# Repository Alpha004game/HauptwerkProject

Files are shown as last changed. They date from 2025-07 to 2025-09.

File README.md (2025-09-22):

# HauptwerkProject

**STATUS: on going**

Progetto open source per la gestione di una pedaliera MIDI, staffe di espressione e bottoniera compatibili con [Hauptwerk](https://www.hauptwerk.com/), basato su Arduino Pro Micro (ATmega32U4). Il sistema invia messaggi MIDI tramite USB grazie alla libreria `MIDIUSB.h`.

## Contenuto del Progetto

- pedaliera a 30/32 note tramite shift register 74HC165
- **3 Staffe di espressione** analogiche con LED indicatori a segmenti (shift register 74HC595)
- Bottoniera per pedaletti e pulsantini sulle tastiere
- **Output MIDI-USB** compatibile con Hauptwerk, GrandOrgue, o qualsiasi DAW

## Requisiti Hardware

- Arduino Pro Micro (ATmega32U4) – obbligatorio per la libreria MIDIUSB X2
- Shift register 74HC165 (input bottoniera) X8
- Shift register 74HC595 (output LED staffe) X3
- potenziometri lineari o sensori analogici per staffe X3
- contattiera per pedaliera di tipo reed switch o sensori hall X30/x32
- LED per visualizzazione livelli staffa (opzionale) X24

### Librerie Arduino
Assicurati di avere installato:

- [`MIDIUSB`](https://github.com/arduino-libraries/MIDIUSB) (via Library Manager)

## 👤 Autore

**Francesco Patti**  
[GitHub](https://github.com/Alpha004game)

🔗 *Compatibile con Hauptwerk™, GrandOrgue, Reaper, Kontakt, e qualsiasi DAW/MIDI host.*

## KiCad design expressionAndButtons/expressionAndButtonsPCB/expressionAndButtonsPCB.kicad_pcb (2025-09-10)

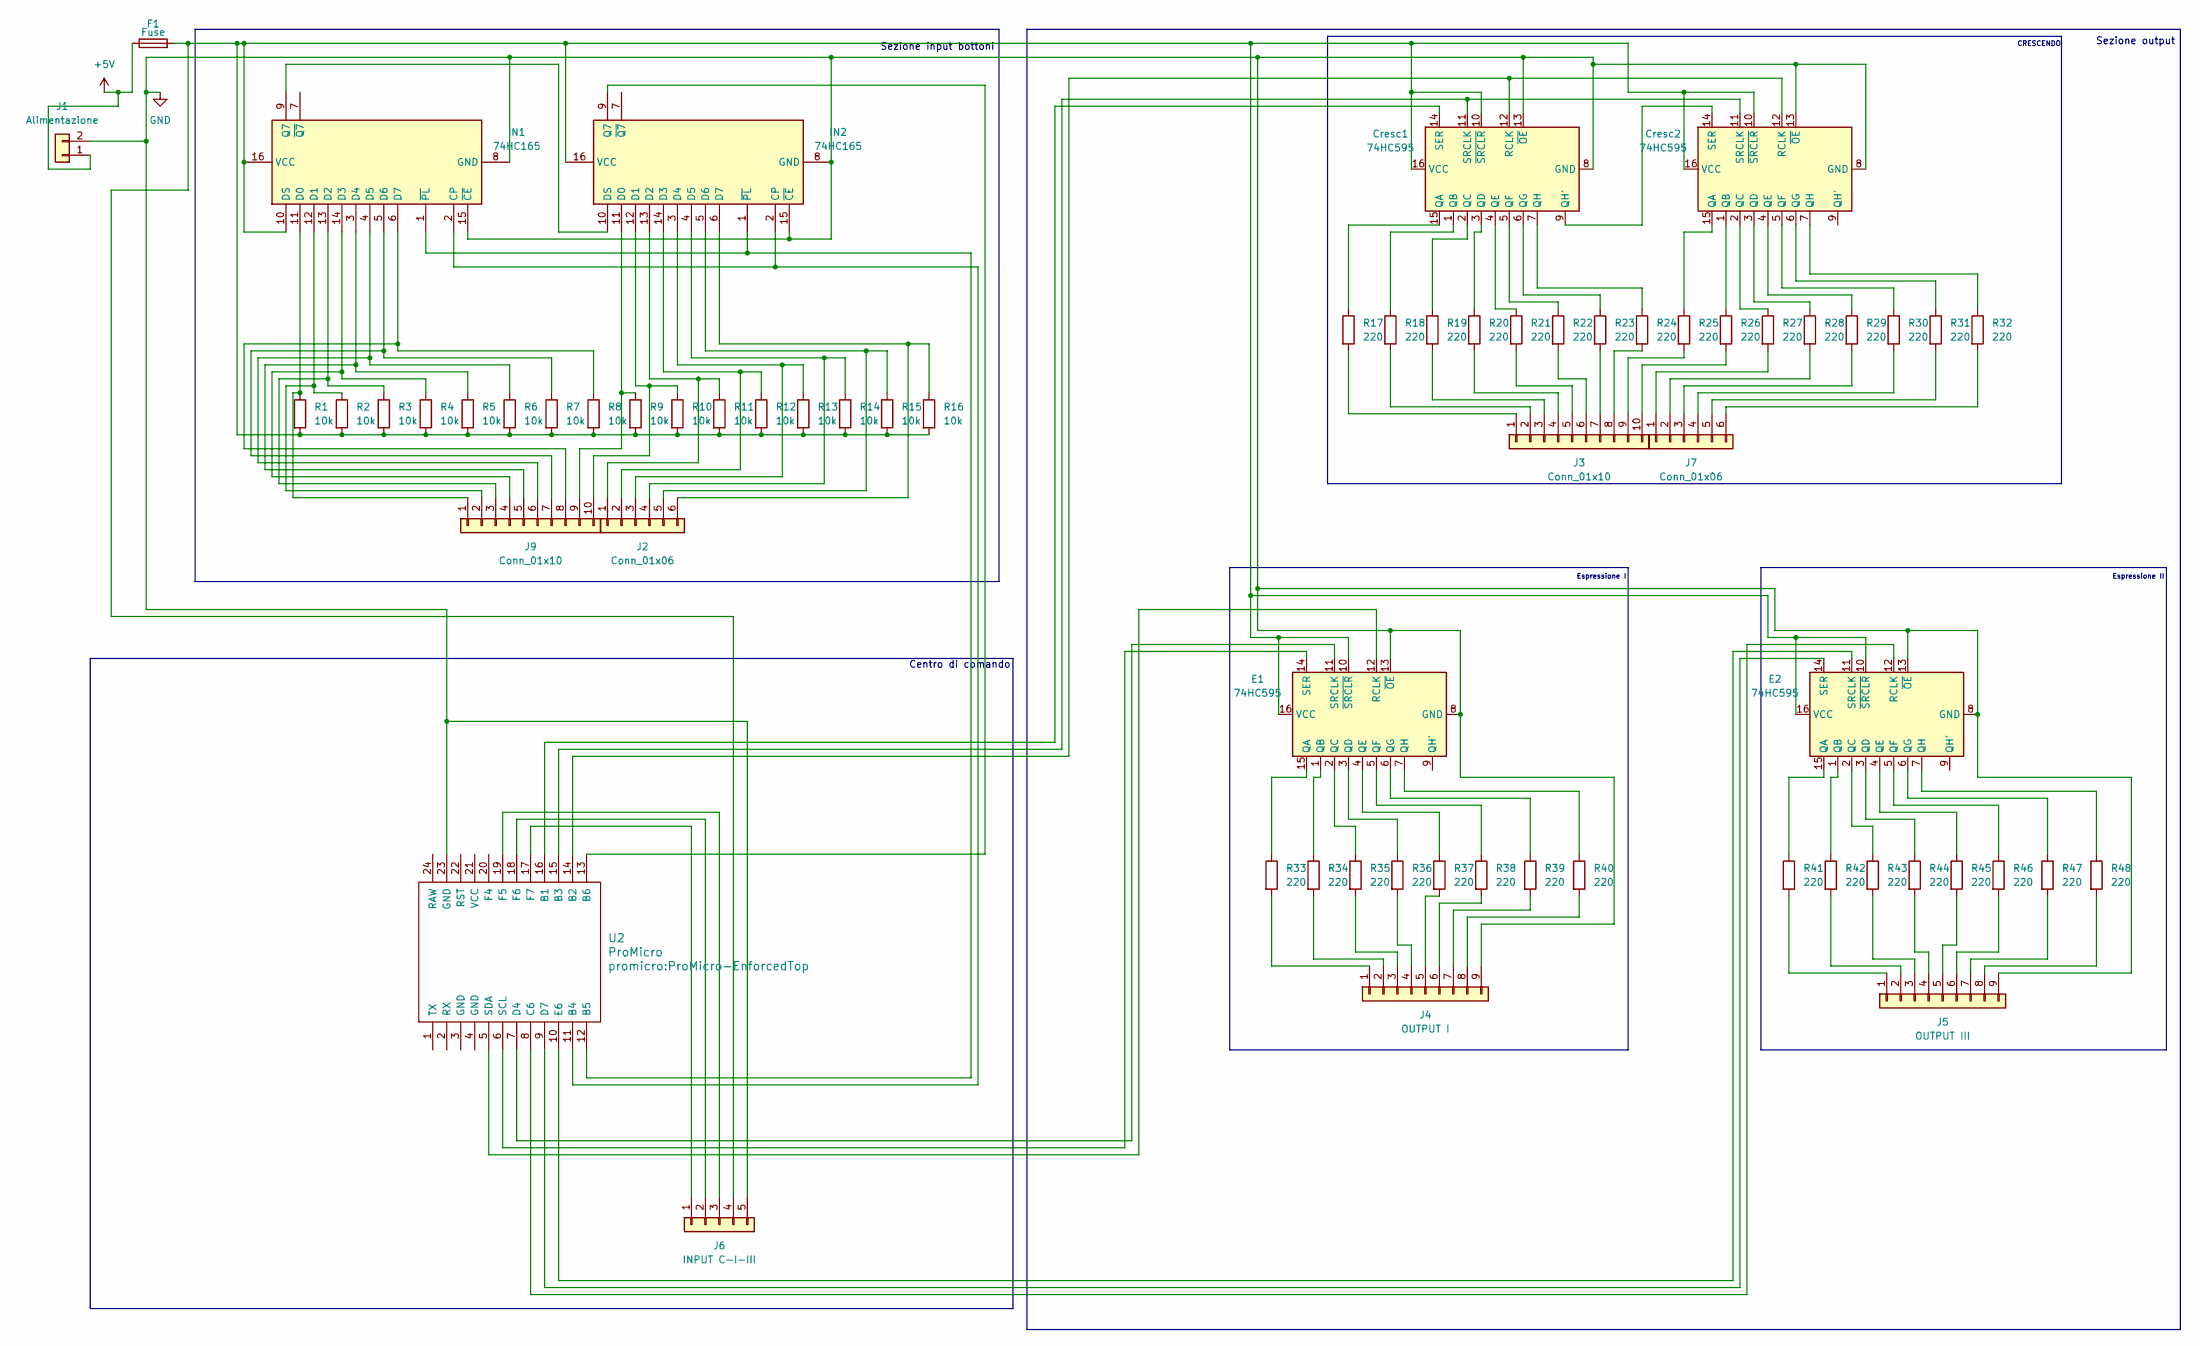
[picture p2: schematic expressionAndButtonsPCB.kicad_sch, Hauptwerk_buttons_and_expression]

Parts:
Cresc1, Cresc2: 74HC595; DIP-16_W7.62mm
E1, E2: 74HC595; DIP-16_W7.62mm
F1: Fuse; Fuseholder_Cylinder-5x20mm_Schurter_0031_8201_Horizontal_Op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
IN1, IN2: 74HC165; DIP-16_W7.62mm
J1: Alimentazione; TerminalBlock_Phoenix_MPT-0,5-2-2.54_1x02_P2.54mm_Horizontal
J2, J7: Conn_01x06; TerminalBlock_Phoenix_MPT-0,5-6-2.54_1x06_P2.54mm_Horizontal
J3, J9: Conn_01x10; TerminalBlock_Phoenix_MPT-0,5-10-2.54_1x10_P2.54mm_Horizont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
J4: OUTPUT I; TerminalBlock_Phoenix_MPT-0,5-9-2.54_1x09_P2.54mm_Horizontal
J5: OUTPUT III; TerminalBlock_Phoenix_MPT-0,5-9-2.54_1x09_P2.54mm_Horizontal
J6: INPUT C-I-III; TerminalBlock_Phoenix_MPT-0,5-5-2.54_1x05_P2.54mm_Horizontal
R1, R2, R3, R4, R5, R6, R7, R8, R9, R10, R11, R12, R13, R14, R15, R16: 10k; R_Axial_DIN0207_L6.3mm_D2.5mm_P7.62mm_Horizontal
R17, R18, R19, R20, R21, R22, R23, R24, R25, R26, R27, R28, R29, R30, R31, R32, R33, R34, R35, R36, R37, R38, R39, R40, R41, R42, R43, R44, R45, R46, R47, R48: 220; R_Axial_DIN0207_L6.3mm_D2.5mm_P7.62mm_Horizontal
U2: ProMicro; ProMicro-EnforcedTop

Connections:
+5V: F1.1, J1.1
GND: Cresc1.8 (GND), Cresc1.13 (~OE), Cresc2.8 (GND), Cresc2.13 (~OE), E1.8 (GND), E1.13 (~OE), E2.8 (GND), E2.13 (~OE), IN1.8 (GND), IN1.15 (~CE), IN2.8 (GND), IN2.15 (~CE), J1.2, J4.9, J5.9, J6.5, U2.23 (GND)
unnamed: Cresc1.15 (QA), R17.1
unnamed: Cresc1.1 (QB), R18.1
unnamed: Cresc1.2 (QC), R19.1
unnamed: Cresc1.3 (QD), R20.1
unnamed: Cresc1.4 (QE), R21.1
unnamed: Cresc1.5 (QF), R22.1
unnamed: Cresc1.6 (QG), R23.1
unnamed: Cresc1.9 (QH'), Cresc2.14 (SER)
unnamed: Cresc1.7 (QH), R24.1
unnamed: Cresc1.12 (RCLK), Cresc2.12 (RCLK), U2.14 (B2)
unnamed: Cresc1.14 (SER), U2.16 (B1)
unnamed: Cresc1.11 (SRCLK), Cresc2.11 (SRCLK), U2.15 (B3)
unnamed: Cresc1.10 (~SRCLR), Cresc1.16 (VCC), Cresc2.10 (~SRCLR), Cresc2.16 (VCC), E1.10 (~SRCLR), E1.16 (VCC), E2.10 (~SRCLR), E2.16 (VCC), F1.2, IN1.10 (DS), IN1.16 (VCC), IN2.16 (VCC), J6.4, R1.2, R2.2, R3.2, R4.2, R5.2, R6.2, R7.2, R8.2, R9.2, R10.2, R11.2, R12.2, R13.2, R14.2, R15.2, R16.2
unnamed: Cresc2.15 (QA), R25.1
unnamed: Cresc2.1 (QB), R26.1
unnamed: Cresc2.2 (QC), R27.1
unnamed: Cresc2.3 (QD), R28.1
unnamed: Cresc2.4 (QE), R29.1
unnamed: Cresc2.5 (QF), R30.1
unnamed: Cresc2.6 (QG), R31.1
unnamed: Cresc2.7 (QH), R32.1
unnamed: E1.15 (QA), R33.1
unnamed: E1.1 (QB), R34.1
unnamed: E1.2 (QC), R35.1
unnamed: E1.3 (QD), R36.1
unnamed: E1.4 (QE), R37.1
unnamed: E1.5 (QF), R38.1
unnamed: E1.6 (QG), R39.1
unnamed: E1.7 (QH), R40.1
unnamed: E1.12 (RCLK), U2.5 (SDA)
unnamed: E1.14 (SER), U2.6 (SCL)
unnamed: E1.11 (SRCLK), U2.7 (D4)
unnamed: E2.15 (QA), R41.1
unnamed: E2.1 (QB), R42.1
unnamed: E2.2 (QC), R43.1
unnamed: E2.3 (QD), R44.1
unnamed: E2.4 (QE), R45.1
unnamed: E2.5 (QF), R46.1
unnamed: E2.6 (QG), R47.1
unnamed: E2.7 (QH), R48.1
unnamed: E2.12 (RCLK), U2.8 (C6)
unnamed: E2.14 (SER), U2.9 (D7)
unnamed: E2.11 (SRCLK), U2.10 (E6)
unnamed: IN1.2 (CP), IN2.2 (CP), U2.11 (B4)
unnamed: IN1.11 (D0), J9.1, R1.1
unnamed: IN1.12 (D1), J9.2, R2.1
unnamed: IN1.13 (D2), J9.3, R3.1
unnamed: IN1.14 (D3), J9.4, R4.1
unnamed: IN1.3 (D4), J9.5, R5.1
unnamed: IN1.4 (D5), J9.6, R6.1
unnamed: IN1.5 (D6), J9.7, R7.1
unnamed: IN1.6 (D7), J9.8, R8.1
unnamed: IN1.9 (Q7), IN2.10 (DS)
unnamed: IN1.1 (~PL), IN2.1 (~PL), U2.12 (B5)
unnamed: IN2.11 (D0), J9.9, R9.1
unnamed: IN2.12 (D1), J9.10, R10.1
unnamed: IN2.13 (D2), J2.1, R11.1
unnamed: IN2.14 (D3), J2.2, R12.1
unnamed: IN2.3 (D4), J2.3, R13.1
unnamed: IN2.4 (D5), J2.4, R14.1
unnamed: IN2.5 (D6), J2.5, R15.1
unnamed: IN2.6 (D7), J2.6, R16.1
unnamed: IN2.9 (Q7), U2.13 (B6)
unnamed: J3.1, R17.2
unnamed: J3.2, R18.2
unnamed: J3.3, R19.2
unnamed: J3.4, R20.2
unnamed: J3.5, R21.2
unnamed: J3.6, R22.2
unnamed: J3.7, R23.2
unnamed: J3.8, R24.2
unnamed: J3.9, R25.2
unnamed: J3.10, R26.2
unnamed: J4.1, R33.2
unnamed: J4.2, R34.2
unnamed: J4.3, R35.2
unnamed: J4.4, R36.2
unnamed: J4.5, R37.2
unnamed: J4.6, R38.2
unnamed: J4.7, R39.2
unnamed: J4.8, R40.2
unnamed: J5.1, R41.2
unnamed: J5.2, R42.2
unnamed: J5.3, R43.2
unnamed: J5.4, R44.2
unnamed: J5.5, R45.2
unnamed: J5.6, R46.2
unnamed: J5.7, R47.2
unnamed: J5.8, R48.2
unnamed: J6.1, U2.17 (F7)
unnamed: J6.2, U2.18 (F6)
unnamed: J6.3, U2.19 (F5)
unnamed: J7.1, R27.2
unnamed: J7.2, R28.2
unnamed: J7.3, R29.2
unnamed: J7.4, R30.2
unnamed: J7.5, R31.2
unnamed: J7.6, R32.2

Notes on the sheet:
Espressione I
CRESCENDO
Sezione output
Centro di comando
Sezione input bottoni
Espressione II

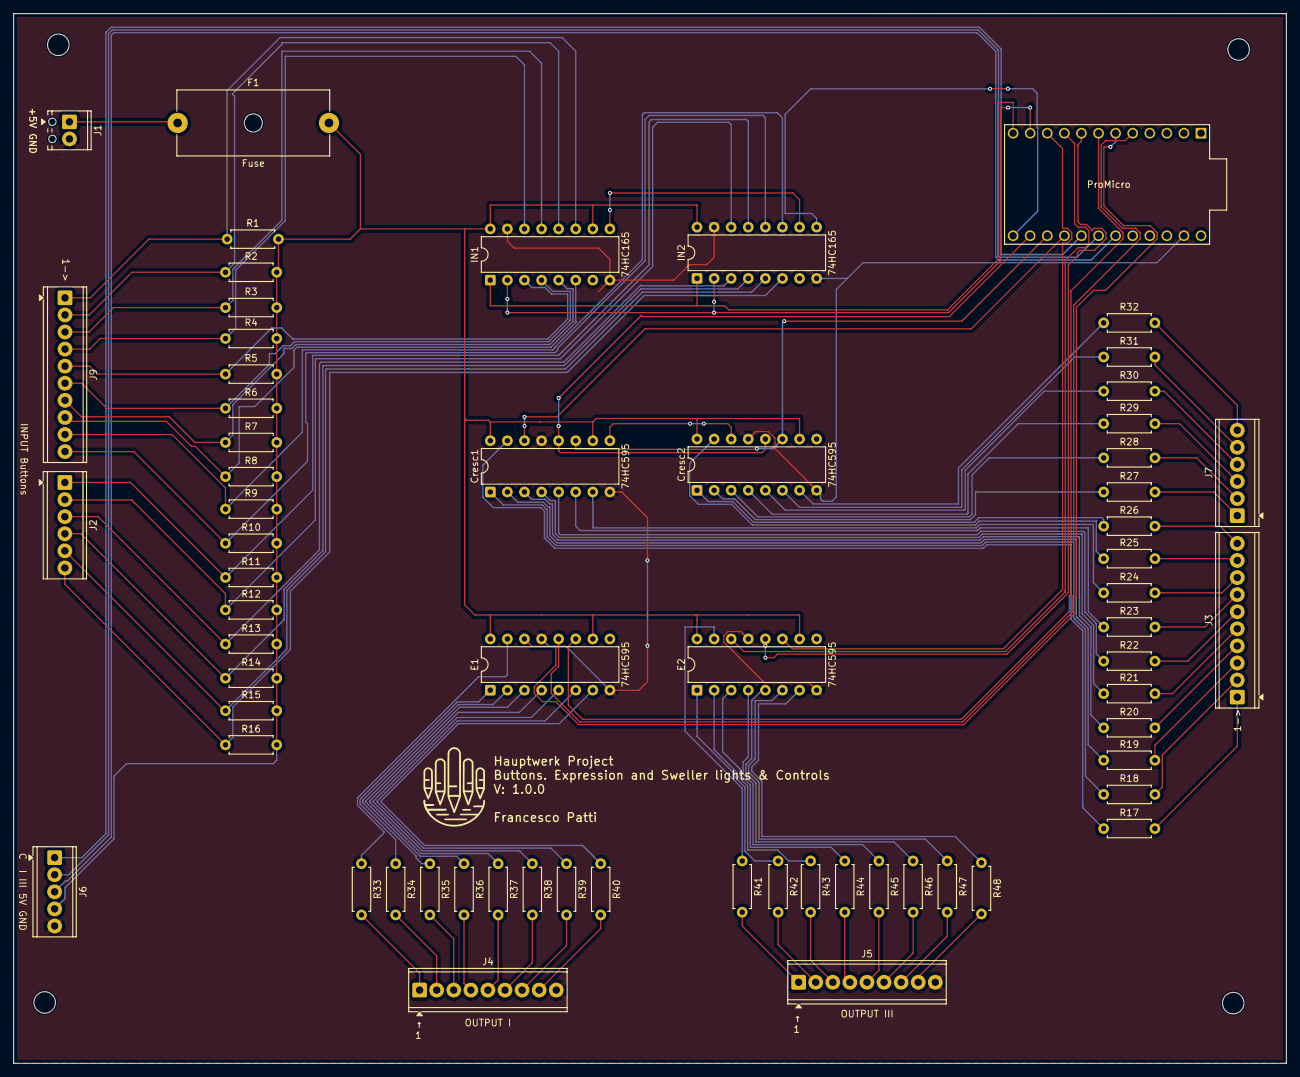
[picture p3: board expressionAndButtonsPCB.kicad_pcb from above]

Board: 2 copper layers, 189.2 x 156.1 mm, 64 parts (0 on the bottom side), 100 nets.

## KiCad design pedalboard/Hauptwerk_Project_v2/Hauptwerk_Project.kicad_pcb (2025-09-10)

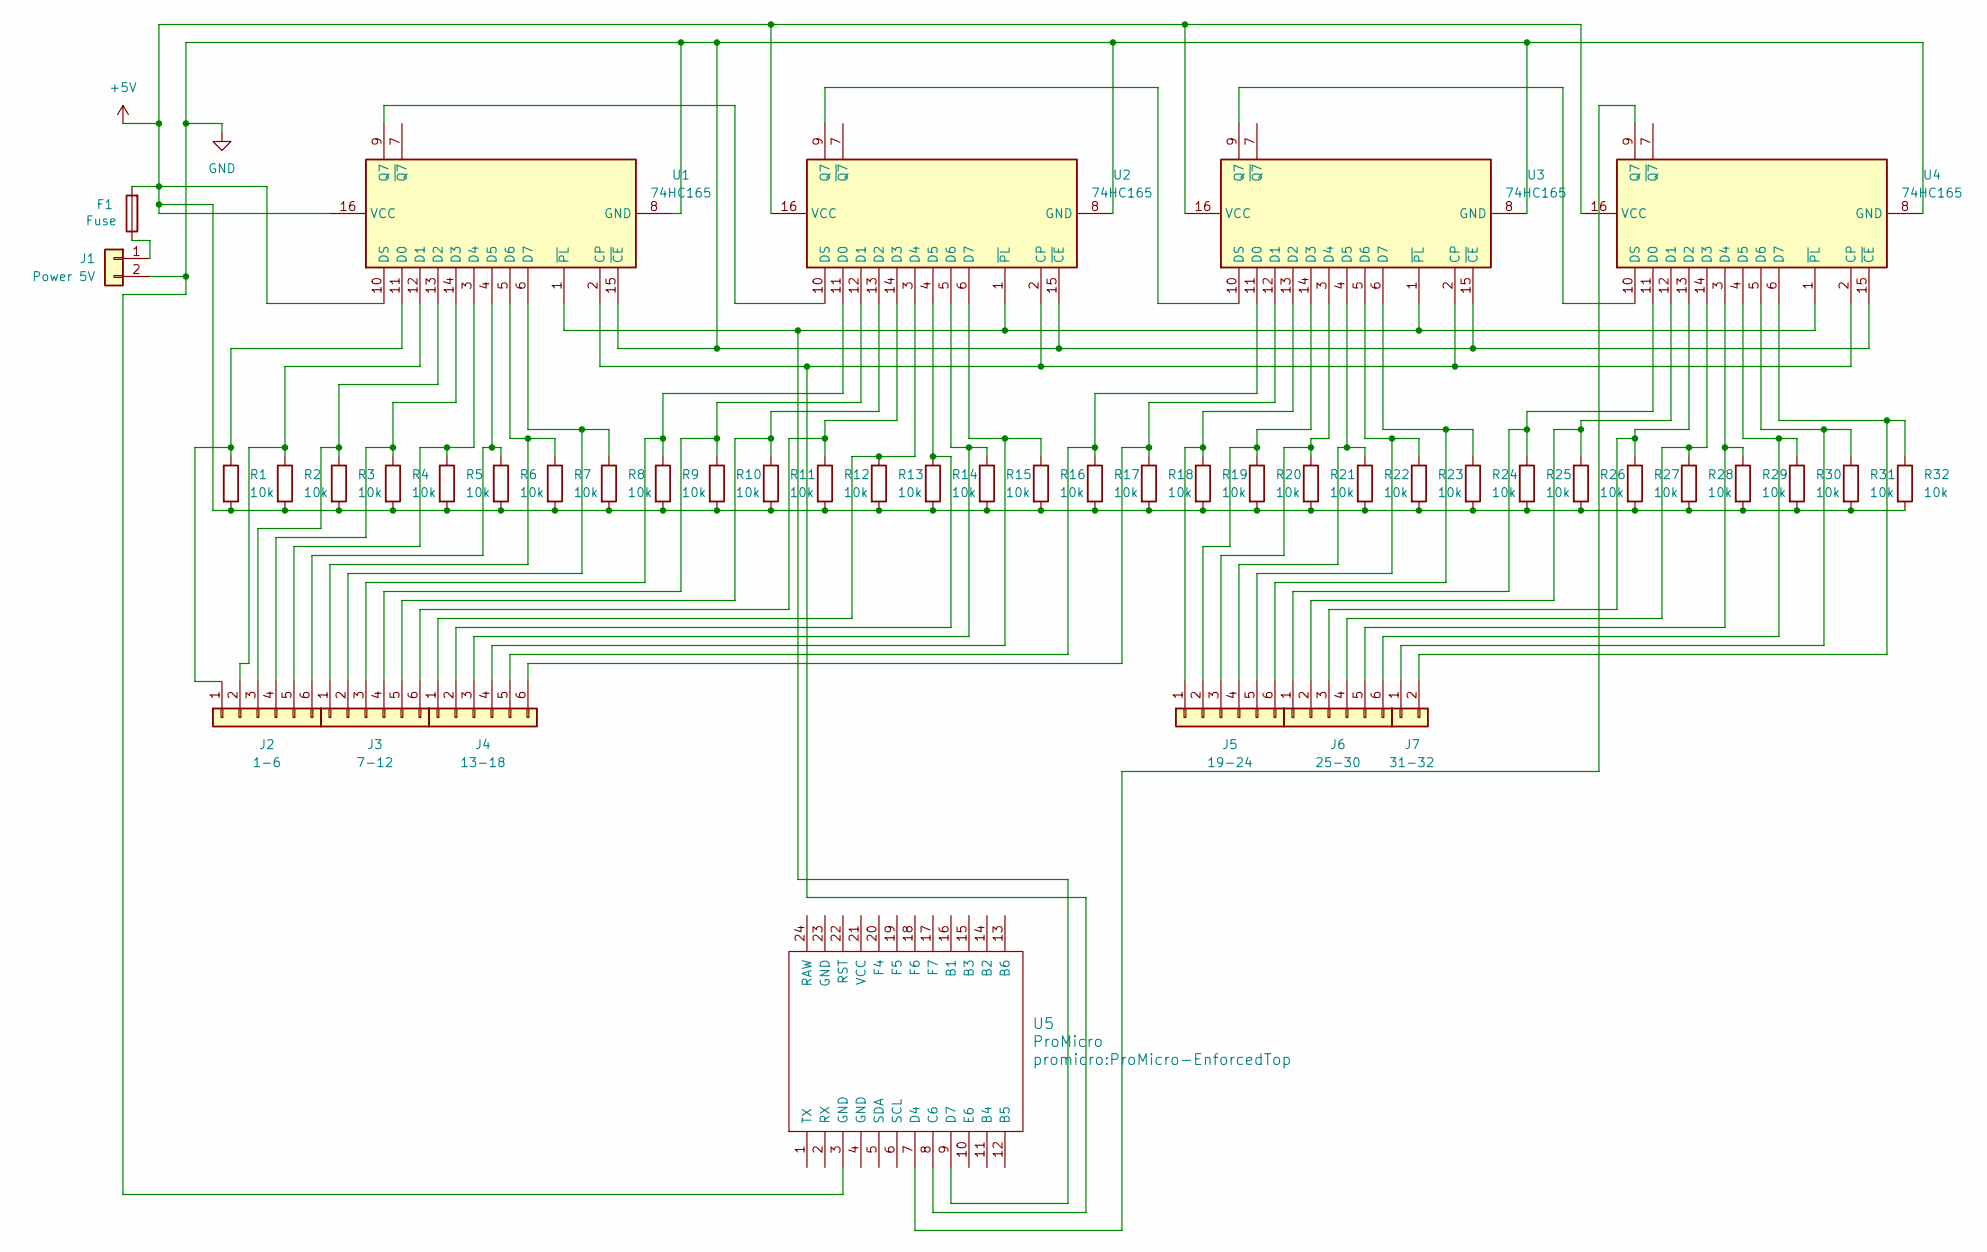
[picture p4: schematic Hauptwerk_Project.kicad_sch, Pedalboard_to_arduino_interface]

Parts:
F1: Fuse; Fuseholder_Cylinder-5x20mm_Schurter_0031_8201_Horizontal_Op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
J1: Power 5V; TerminalBlock_Phoenix_MKDS-1,5-2-5.08_1x02_P5.08mm_Horizont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
J2: 1-6; TerminalBlock_Phoenix_MKDS-1,5-6-5.08_1x06_P5.08mm_Horizont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
J3: 7-12; TerminalBlock_Phoenix_MKDS-1,5-6-5.08_1x06_P5.08mm_Horizont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
J4: 13-18; TerminalBlock_Phoenix_MKDS-1,5-6-5.08_1x06_P5.08mm_Horizont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
J5: 19-24; TerminalBlock_Phoenix_MKDS-1,5-6-5.08_1x06_P5.08mm_Horizont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
J6: 25-30; TerminalBlock_Phoenix_MKDS-1,5-6-5.08_1x06_P5.08mm_Horizont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
J7: 31-32; TerminalBlock_Phoenix_MKDS-1,5-2-5.08_1x02_P5.08mm_Horizont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
R1, R2, R3, R4, R5, R6, R7, R8, R9, R10, R11, R12, R13, R14, R15, R16, R17, R18, R19, R20, R21, R22, R23, R24, R25, R26, R27, R28, R29, R30, R31, R32: 10k; R_Axial_DIN0207_L6.3mm_D2.5mm_P7.62mm_Horizontal
U1, U2, U3, U4: 74HC165; DIP-16_W7.62mm
U5: ProMicro; ProMicro-EnforcedTop

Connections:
+5V: F1.2, R1.2, R2.2, R3.2, R4.2, R5.2, R6.2, R7.2, R8.2, R9.2, R10.2, R11.2, R12.2, R13.2, R14.2, R15.2, R16.2, R17.2, R18.2, R19.2, R20.2, R21.2, R22.2, R23.2, R24.2, R25.2, R26.2, R27.2, R28.2, R29.2, R30.2, R31.2, R32.2, U1.10 (DS), U1.16 (VCC), U2.16 (VCC), U3.16 (VCC), U4.16 (VCC)
GND: J1.2, U1.8 (GND), U1.15 (~CE), U2.8 (GND), U2.15 (~CE), U3.8 (GND), U3.15 (~CE), U4.8 (GND), U4.15 (~CE), U5.3 (GND)
unnamed: F1.1, J1.1
unnamed: J2.1, R1.1, U1.11 (D0)
unnamed: J2.2, R2.1, U1.12 (D1)
unnamed: J2.3, R3.1, U1.13 (D2)
unnamed: J2.4, R4.1, U1.14 (D3)
unnamed: J2.5, R5.1, U1.3 (D4)
unnamed: J2.6, R6.1, U1.4 (D5)
unnamed: J3.1, R7.1, U1.5 (D6)
unnamed: J3.2, R8.1, U1.6 (D7)
unnamed: J3.3, R9.1, U2.11 (D0)
unnamed: J3.4, R10.1, U2.12 (D1)
unnamed: J3.5, R11.1, U2.13 (D2)
unnamed: J3.6, R12.1, U2.14 (D3)
unnamed: J4.1, R13.1, U2.3 (D4)
unnamed: J4.2, R14.1, U2.4 (D5)
unnamed: J4.3, R15.1, U2.5 (D6)
unnamed: J4.4, R16.1, U2.6 (D7)
unnamed: J4.5, R17.1, U3.11 (D0)
unnamed: J4.6, R18.1, U3.12 (D1)
unnamed: J5.1, R19.1, U3.13 (D2)
unnamed: J5.2, R20.1, U3.14 (D3)
unnamed: J5.3, R21.1, U3.3 (D4)
unnamed: J5.4, R22.1, U3.4 (D5)
unnamed: J5.5, R23.1, U3.5 (D6)
unnamed: J5.6, R24.1, U3.6 (D7)
unnamed: J6.1, R25.1, U4.11 (D0)
unnamed: J6.2, R26.1, U4.12 (D1)
unnamed: J6.3, R27.1, U4.13 (D2)
unnamed: J6.4, R28.1, U4.14 (D3)
unnamed: J6.5, R29.1, U4.3 (D4)
unnamed: J6.6, R30.1, U4.4 (D5)
unnamed: J7.1, R31.1, U4.5 (D6)
unnamed: J7.2, R32.1, U4.6 (D7)
unnamed: U1.2 (CP), U2.2 (CP), U3.2 (CP), U4.2 (CP), U5.8 (C6)
unnamed: U1.9 (Q7), U2.10 (DS)
unnamed: U1.1 (~PL), U2.1 (~PL), U3.1 (~PL), U4.1 (~PL), U5.9 (D7)
unnamed: U2.9 (Q7), U3.10 (DS)
unnamed: U3.9 (Q7), U4.10 (DS)
unnamed: U4.9 (Q7), U5.7 (D4)

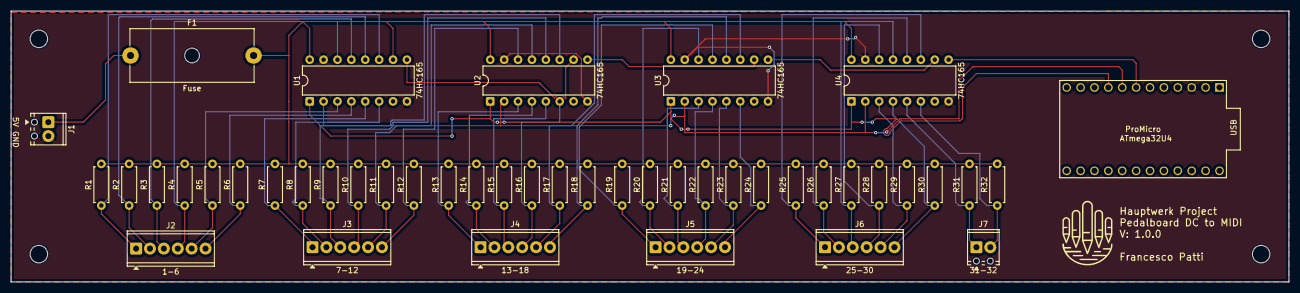
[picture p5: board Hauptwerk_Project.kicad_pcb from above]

Board: 2 copper layers, 233.7 x 49.5 mm, 45 parts (0 on the bottom side), 41 nets.

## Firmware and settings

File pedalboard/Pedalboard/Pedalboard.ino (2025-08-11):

/*
       ---PROGETTO HAUPTWERK---
       Titolo: pedalboardToArduinoToMidi
       Descrizione: Codice necessario al funzionamento della pedaliera (30/32 note)
       Nota: 
       Autore: Francesco Patti
       Versione: 1.5.0
       Arduino: Arduino Pro Micro con 32U4
*/
#include "MIDIUSB.h"

/*   ---MIDI SETTINGS---   */
#define MIDI_CHANNEL 0
#define BASENOTE 36 // Do2 (Calibrare a seconda del funzionamento di hauptwerk)

/*   ----Pedalboard config---   */
#define NUM_CHIPS 4
#define LATCHPIN 6
#define CLOCKPIN 5
#define DATAPIN 4
const int NUM_KEYS = 8 * NUM_CHIPS;

/* ---State memorizer---*/
bool lastState[NUM_KEYS];
byte values[NUM_CHIPS];


void setup() {
  pinMode(LATCHPIN, OUTPUT);
  pinMode(CLOCKPIN, OUTPUT);
  pinMode(DATAPIN, INPUT);

  for (int i = 0; i < NUM_KEYS; i++) {
    lastState[i] = false;
  }

  for(int i=0; i<NUM_CHIPS; i++)
  {
    values[i]=255; //Logica invertita per il PULLUP
  }
}

void loop() {
  digitalWrite(LATCHPIN, LOW);   // Blocca input
  delayMicroseconds(10);
  digitalWrite(LATCHPIN, HIGH);  // Carica i dati
  delayMicroseconds(10);

  // Leggo tutti i chip
  for (int chip = 0; chip < NUM_CHIPS; chip++) {
    //values[chip] = shiftIn(DATAPIN, CLOCKPIN, MSBFIRST);
    values[chip]=readShiftRegister();
  }

  // Ora scorri ogni bit per determinare il singolo stato di ogni pedale
  for (int i = 0; i < NUM_KEYS; i++) {
    int chipIndex = i / 8;
    int bitIndex = 7 - (i % 8);


    bool current = bitRead(values[chipIndex], bitIndex) == 0;

    if (current != lastState[i]) {
      lastState[i] = current;

      int reversedIndex = (NUM_KEYS - 1) - i;

      if (current) {
        noteOn(MIDI_CHANNEL, BASENOTE + reversedIndex, 100);
      } else {
        noteOff(MIDI_CHANNEL, BASENOTE + reversedIndex, 0);
      }

      MidiUSB.flush();
    }
  }
}

void noteOn(byte channel, byte pitch, byte velocity) {
  midiEventPacket_t noteOnMsg = {0x09, 0x90 | channel, pitch, velocity};
  MidiUSB.sendMIDI(noteOnMsg);
}

void noteOff(byte channel, byte pitch, byte velocity) {
  midiEventPacket_t noteOffMsg = {0x08, 0x80 | channel, pitch, velocity};
  MidiUSB.sendMIDI(noteOffMsg);
}

byte readShiftRegister() {
  byte data = 0;
  for (int i = 0; i < 8; i++) {
    data <<= 1;
    data |= digitalRead(DATAPIN);
    digitalWrite(CLOCKPIN, HIGH);
    delayMicroseconds(1);
    digitalWrite(CLOCKPIN, LOW);
    delayMicroseconds(1);
  }
  return data;
}

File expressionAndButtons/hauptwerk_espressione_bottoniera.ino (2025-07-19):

/*
       ---PROGETTO HAUPTWERK---
       Titolo: buttonsAndExpression
       Descrizione: Codice necessario al funzionamento delle staffe e della bottoniera
       Nota: Bottoniera per input PULLUP
       Autore: Francesco Patti
       Versione: 1.0.0
       Arduino: Arduino Pro Micro con 32U4
*/

/*
PEDALETTI DA IMPLEMENTARE

CICCIO:
+
-
10 aggiustabili
P->I, P->II, P->III
I->III
II->I, II->III

TUTTI
Ann gen
Fiss

Totale: 21 (Capire distribuzione tra tastiere e pedaletti)

FABIO:
+
-
10 aggiustabili
P->I, P->II, P->III, P->IV
I->III, I->IV
II->I, II->III, II->IV
III->IV

TUTTI
Ann gen
Fiss

Totale: 25 (Capire distribuizione tra tastiere e pedaletti)


*/

#include "MIDIUSB.h"

/*---Sezione Bottoniera---*/
#define CLOCK_B_PIN 8
#define LATCH_B_PIN 9
#define DATA_B_PIN 10
#define P_CHANNEL 4

#define NUM_CHIPS 4
#define BASENOTE 36 //"Nota" di base per riferimento

const int NUM_BUTTONS = 8 * NUM_CHIPS;
bool lastButtonState[NUM_BUTTONS];
byte buttonValues[NUM_CHIPS];
/*---Fine Sezione Bottoniera---*/



/*---Sezione Espressione---*/
#define EXPRESSION_PIN_1 A0 //Crescendo
#define EXPRESSION_PIN_2 A1 //I (III)
#define EXPRESSION_PIN_3 A2 //III (IV)

int lastValue[3] = {-1, -1, -1};

#define SMOOTHING 4  
#define MIDI_CONTROLLER 11  //Controller

//SW
#define LATCH_C_PIN 14 //ST_CP
#define DATA_C_PIN 15 //DS
#define CLOCK_C_PIN 16 //SH_CP
#define C_CHANNEL 1
#define C_CONTROLLER 19

//I(III)
#define LATCH_E1_PIN 2 
#define DATA_E1_PIN 3
#define CLOCK_E1_PIN 4
#define E1_CHANNEL 2
#define E1_CONTROLLER 4

//III(IV)
#define LATCH_E2_PIN 5
#define DATA_E2_PIN 6
#define CLOCK_E2_PIN 7
#define E2_CHANNEL 3
#define E2_CONTROLLER 11

/*---Fine Sezione Espressione---*/


/*---Commons---*/

/*---Fine Commons---*/

void setup() {
  /*COMMON*/
  
  /*END COMMON*/

  /*BUTTON*/
  pinMode(LATCH_B_PIN, OUTPUT);
  pinMode(CLOCK_B_PIN, OUTPUT);
  pinMode(DATA_B_PIN, INPUT);

  for(int i=0; i<NUM_CHIPS; i++)
  {
    lastButtonState[i]=false;
  }
  for(int i=0; i<NUM_CHIPS; i++)
  {
    buttonValues[i]=255;
  }
  /*END BUTTON*/

  /*EXPRESSION*/
  pinMode(EXPRESSION_PIN_1, INPUT);
  pinMode(EXPRESSION_PIN_2, INPUT);
  pinMode(EXPRESSION_PIN_3, INPUT);

  pinMode(CLOCK_C_PIN, OUTPUT);
  pinMode(LATCH_C_PIN, OUTPUT);
  pinMode(DATA_C_PIN, OUTPUT);
  /*END EXPRESSION*/
}

void loop() {
  updateStaffa(EXPRESSION_PIN_1, CLOCK_C_PIN, LATCH_C_PIN, DATA_C_PIN, C_CHANNEL, C_CONTROLLER);
  updateStaffa(EXPRESSION_PIN_2, CLOCK_E1_PIN, LATCH_E1_PIN, DATA_E1_PIN, E1_CHANNEL, E1_CONTROLLER);
  updateStaffa(EXPRESSION_PIN_3, CLOCK_E2_PIN, LATCH_E2_PIN, DATA_E2_PIN, E2_CHANNEL, E2_CONTROLLER);
  //updateBottoniera(CLOCK_B_PIN, LATCH_B_PIN, DATA_B_PIN, P_CHANNEL);

}

//---------------------------------------------BUTTON-------------------------------------------------------
void updateBottoniera(int clockPin, int latchPin, int dataPin, int midiChannel)
{
  digitalWrite(latchPin, LOW);
  delayMicroseconds(5);
  digitalWrite(latchPin, HIGH);

  for (int i = 0; i < NUM_BUTTONS; i++) {
    buttonValues[i] = shiftIn(dataPin, clockPin, MSBFIRST);
  }

  for (int i = 0; i < NUM_BUTTONS; i++) {
    int chipIndex = i / 8;
    int bitIndex = 7 - (i % 8);

    bool current = bitRead(buttonValues[chipIndex], bitIndex) == 0;

    if (current != lastButtonState[i]) {
      lastButtonState[i] = current;

      if (current) {
        noteOn(midiChannel, BASENOTE + i, 100);
      } else {
        noteOff(midiChannel, BASENOTE + i, 0);
      }

      MidiUSB.flush();
    }
  }
}

void noteOn(byte channel, byte pitch, byte velocity) {
  midiEventPacket_t noteOnMsg = {0x09, 0x90 | channel, pitch, velocity};
  MidiUSB.sendMIDI(noteOnMsg);
}

void noteOff(byte channel, byte pitch, byte velocity) {
  midiEventPacket_t noteOffMsg = {0x08, 0x80 | channel, pitch, velocity};
  MidiUSB.sendMIDI(noteOffMsg);
}
//----------------------------------------------------------------------------------------------------------


//---------------------------------------------EXPRESSION---------------------------------------------------
void updateStaffa(int analogPin, int clockPin, int latchPin, int dataPin, int midiChannel, int controller) {
  int index;
  switch (analogPin) {
    case A0:
      index = 0;
      break;
    case A1:
      index = 1;
      break;
    case A2:
      index = 2;
      break;
  }

  int analogValue = analogRead(analogPin);
  int midiValue = map(analogValue, 0, 1023, 0, 127);

  if (abs(midiValue - lastValue[index]) >= SMOOTHING) {
    lastValue[index] = midiValue;
    
    
    sendControlChange(controller, midiValue, midiChannel);
    updateLuci(clockPin, latchPin, dataPin, midiValue);
  }
}

void updateLuci(int clockPin, int latchPin, int dataPin, int value) {
  byte binaryValue = getBinaryValuePerStaffa(value);

  digitalWrite(latchPin, LOW);
  shiftOut(dataPin, clockPin, MSBFIRST, binaryValue);
  digitalWrite(latchPin, HIGH);
}

byte getBinaryValuePerStaffa(int value) {
  if (value >= 0 && value <= 14) {
    return B00000000;
  } else if (value >= 15 && value <= 29) {
    return B00000001;
  } else if (value >= 30 && value <= 44) {
    return B00000011;
  } else if (value >= 45 && value <= 59) {
    return B00000111;
  } else if (value >= 60 && value <= 74) {
    return B00001111;
  } else if (value >= 75 && value <= 89) {
    return B00011111;
  } else if (value >= 90 && value <= 104) {
    return B00111111;
  } else if (value >= 105 && value <= 112) {
    return B01111111;
  } else {
    return B11111111;
  }
}

void sendControlChange(byte control, byte value, byte channel) {
  midiEventPacket_t event = {0x0B, 0xB0 | channel, control, value};

  MidiUSB.sendMIDI(event);
  MidiUSB.flush();
}


//----------------------------------------------------------------------------------------------------------

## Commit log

2025-07-31 Creazione PCB
    Prima versione creata e qualche sistemazione nello schema elettrico
    [Hauptwerk_Project.kicad_pcb, Hauptwerk_Project.kicad_sch]
2025-08-02 Aggiornamento e creazione versione con arduino integrato
    [Hauptwerk_Project.kicad_pcb, Hauptwerk_Project.kicad_sch]
2025-08-02 Creazione progetto per staffe e bottoniera
    [expressionAndButtonsPCB.kicad_pcb, expressionAndButtonsPCB.kicad_sch]
2025-08-11 Fix vari
    [Hauptwerk_Project-B_Cu.gbr, Hauptwerk_Project-B_Mask.gbr, Hauptwerk_Project-B_Paste.gbr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]
2025-08-28 Update dim footprint
    [Hauptwerk_Project-B_Cu.gbr, Hauptwerk_Project-B_Mask.gbr, Hauptwerk_Project-B_Paste.gbr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]
2025-09-01 Progresso bottoniera
    [Hauptwerk_Project-B_Cu.gbr, Hauptwerk_Project-B_Mask.gbr, Hauptwerk_Project-B_Paste.gbr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]
2025-09-02 First version buttons
    [expressionAndButtonsPCB.kicad_pcb, expressionAndButtonsPCB.kicad_sch]
2025-09-10 problem fix
    [Hauptwerk_Project-B_Cu.gbr, Hauptwerk_Project-B_Mask.gbr, Hauptwerk_Project-B_Paste.gbr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]

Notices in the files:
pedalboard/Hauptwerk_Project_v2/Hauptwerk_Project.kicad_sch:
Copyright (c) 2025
